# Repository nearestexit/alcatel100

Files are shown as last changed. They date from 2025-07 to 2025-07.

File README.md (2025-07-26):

# alcatel100

Custom keyboard designed to use the GMK keycaps from the [Alcatel-Lucent MMK](https://deskthority.net/viewtopic.php?t=23887).
Designed in Onshape and KiCad.
Powered by [QMK](https://github.com/qmk/qmk_firmware).

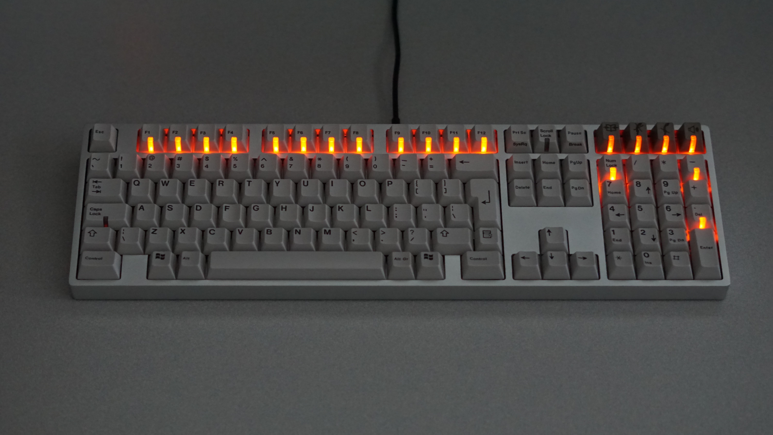
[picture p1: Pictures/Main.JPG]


## Overview
The Alcatel MMK has a beautiful set of keycaps, but the Enter, Backspace, and Right Shift are 0.25u shorter than normal. They are rarely, if ever, used on customs.
The keycaps were originally made by Cherry, but later GMK took over production.

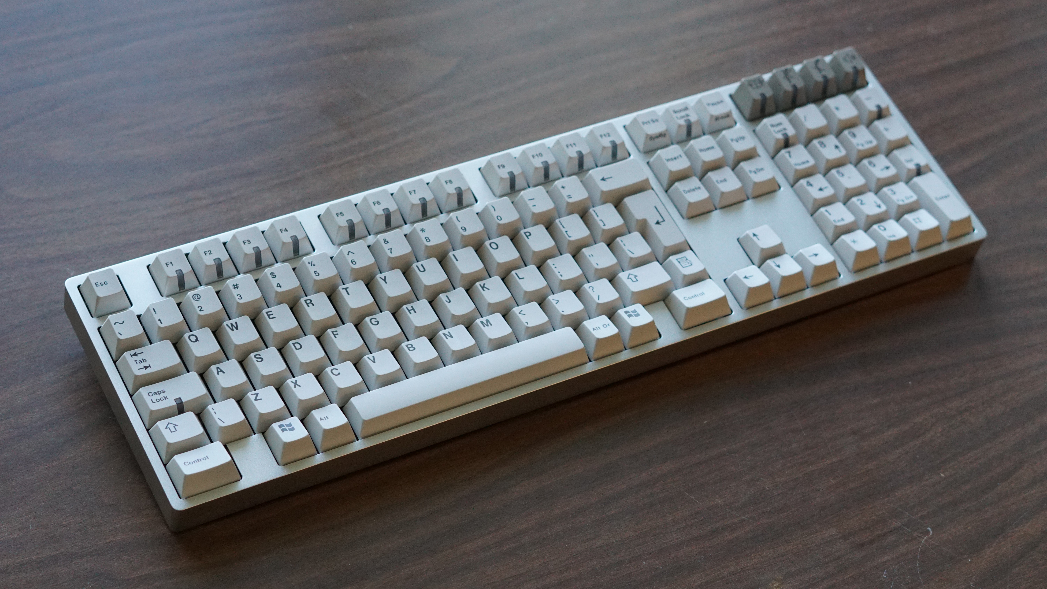
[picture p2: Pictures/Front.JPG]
Front


I designed this for fun. It is not an entry-level keyboard, and it is not intended for a Group Buy.
I'm sharing the production and source files with the goal of serving as a reference for other designers.

combo2

## Design Goals
- Box-on-wedge with seamless sides all around, including the back
- Left half of the keyboard isolated from the right half
- Single-color PWM-dimmable backlight
- Uniform 4.8mm bezels

**Case Source (Onshape):** https://cad.onshape.com/documents/5081b96c77523c56bb0f8f6b/w/91dc47074a8fd3b0ca2e25d0/e/6e8ed4262c52380f9f8bfe9b

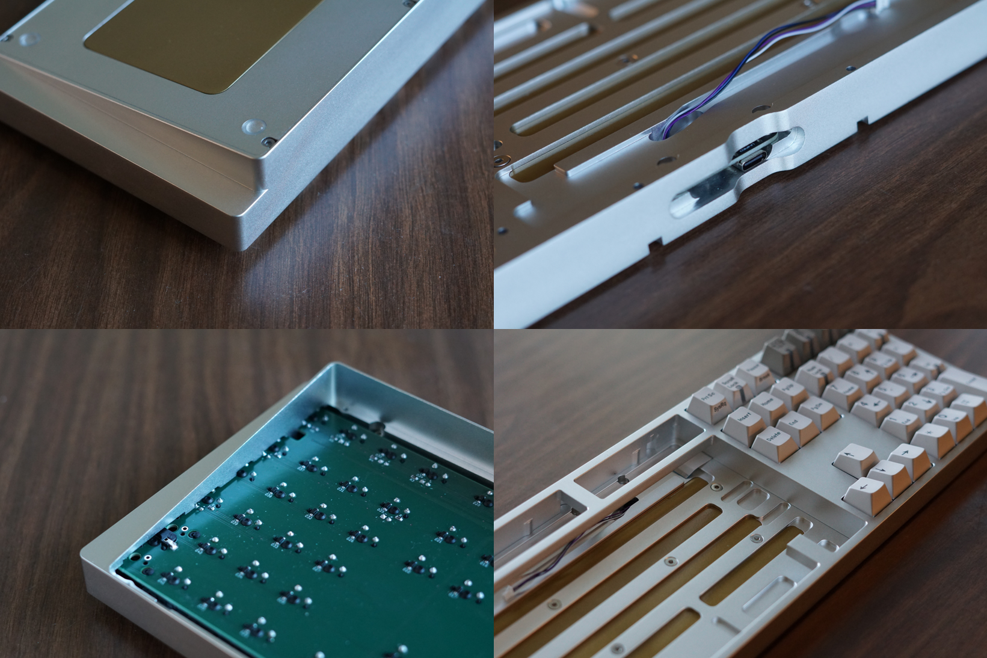
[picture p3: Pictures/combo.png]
Combo


## PCB
The PCB supports both configurations of split right shift, and also split numpad enter. Unfortunately, after the PCB was manufactured, I discovered that the Cherry version of the keyset has a 6.25u spacebar that only has an offset stem, while the GMK version of the keyset has a 6.25u spacebar that supports both centered and offset stems. The PCB and bottom case only support the centered stem location.
I ordered a single bare PCB from EuroCircuits and hand-soldered the components, so I do not have JLCPCB production files available.

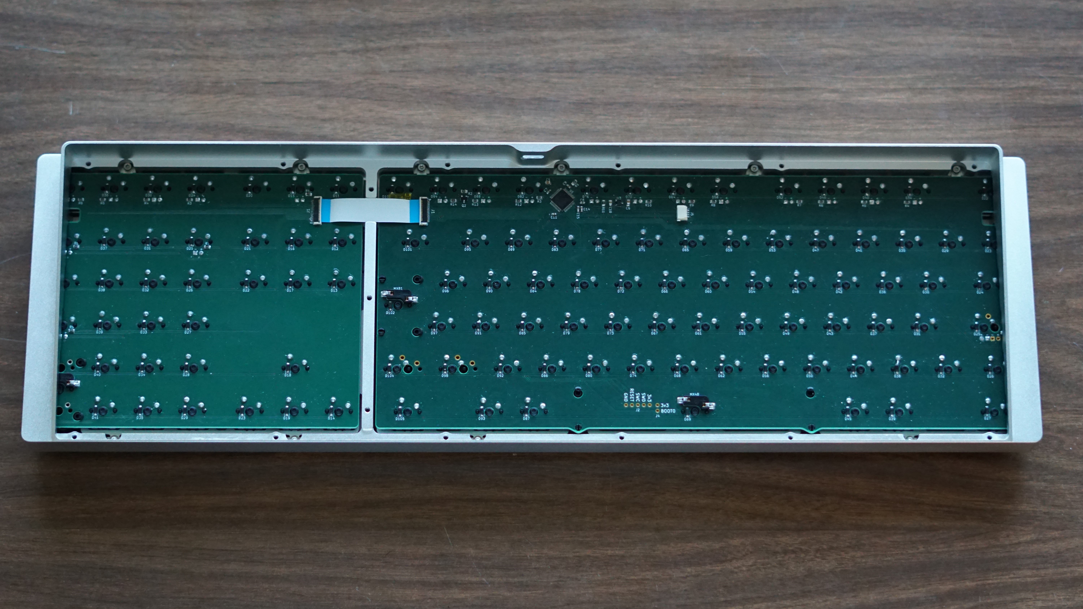
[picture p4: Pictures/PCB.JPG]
PCB


## Bill of Materials

| Item  | Quantity | Link |
| --- | --- | --- |
| Ribbon Cable | 1 | https://www.digikey.com/en/products/detail/molex/0151660207/3281088 |
| 3M SJ5302 | 4  | https://www.3m.com/3M/en_US/p/d/b5005035183/ |
| Unified Daughterboard  | 1  | https://cannonkeys.com/products/unified-daughterboard-and-jst-cable |
| M2.5x0.45x8mm SHCS | 6  | https://www.mcmaster.com/91292A012/ |
| 10cm Molex to JST Cable | 1 | https://cannonkeys.com/products/unified-daughterboard-and-jst-cable |
| M2.5x0.45x16mm SHCS | 1 | https://www.mcmaster.com/91292A018/ |
| M2.5x0.45x20mm SHCS | 6 | https://www.mcmaster.com/91292A019/ |
| M2x0.4x4mm SHCS | 10 | https://www.mcmaster.com/91292A005/ |
| M3x0.5x6mm Countersunk Screw | 5 | https://www.mcmaster.com/92125A126/ |
| M3x0.5x8mm Countersunk Screw | 8 | https://www.mcmaster.com/92125A128/ |

## Backlight

Each lock light is controlled by a separate pin and has a fixed brightness. The remainder of the windowed keys are all on the same PWM dimmable circuit.
I used [these LEDs](https://www.digikey.com/en/products/detail/american-bright-optoelectronics-corporation/BL-B8141-TRS20A/22486924), which have a nice color, but MX LEDs are actually supposed to be 3mm *flangeless* LEDs. These LEDs are *flanged* 3mm. I had to clip off all the flanges (not fun).

backlight

## Firmware

A QMK .bin file is provided for flashing, as well as QMK source files. I can port it to Vial upon request.

## Credits

Everyone in the Keyboard Atelier who has helped me over the past 2 years.

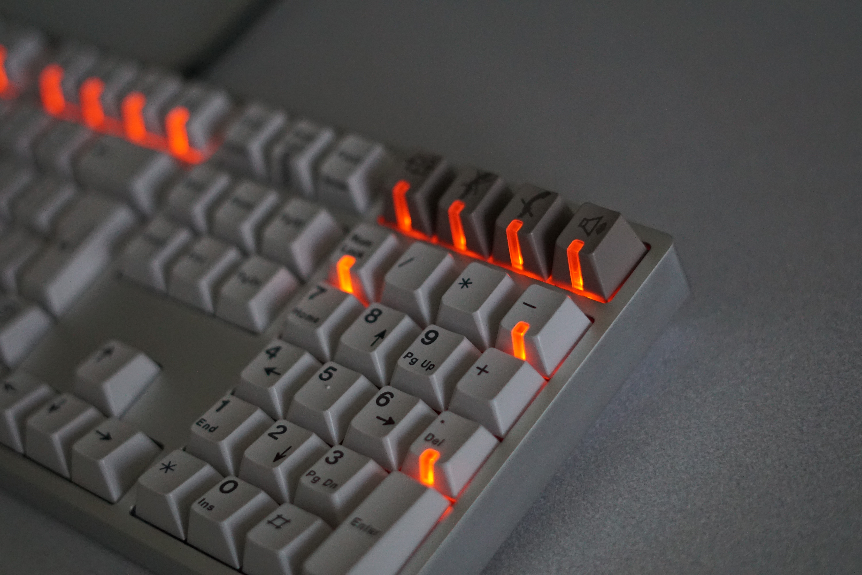
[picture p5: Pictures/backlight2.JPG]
bottom


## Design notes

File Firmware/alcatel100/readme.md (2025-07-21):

# alcatel100

alcatel100

*A short description of the keyboard/project*

* Keyboard Maintainer: [nearestexit](https://github.com/nearestexit)
* Hardware Supported: *The PCBs, controllers supported*
* Hardware Availability: *Links to where you can find this hardware*

Make example for this keyboard (after setting up your build environment):

    make alcatel100:default

Flashing example for this keyboard:

    make alcatel100:default:flash

See the [build environment setup](https://docs.qmk.fm/#/getting_started_build_tools) and the [make instructions](https://docs.qmk.fm/#/getting_started_make_guide) for more information. Brand new to QMK? Start with our [Complete Newbs Guide](https://docs.qmk.fm/#/newbs).

## Bootloader

Enter the bootloader in 3 ways:

* **Bootmagic reset**: Hold down the key at (0,0) in the matrix (usually the top left key or Escape) and plug in the keyboard
* **Physical reset button**: Briefly press the button on the back of the PCB - some may have pads you must short instead
* **Keycode in layout**: Press the key mapped to `QK_BOOT` if it is available

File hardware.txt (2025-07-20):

front case screws
m2.5x8mm alloy steel socket head screws x5
goes through 3.1mm of untapped bottom case before hitting 7mm deep hole, tapped to 6.1mm
https://www.mcmaster.com/91292A012

front (smallest) divider screw 
m2.5x8mm alloy steel socket head screws x1
goes through 1.8mm of untapped bottom case before hitting hole tapped to 9.6mm
https://www.mcmaster.com/91292A012

middle divider screw
m2.5x16 alloy steel socket head screw x1
goes through 7.9mm of untapped bottom case before hitting hole tapped to 9.6mm
https://www.mcmaster.com/91292A018/

rear (longest) divider screw
m2.5x20 alloy steel socket head screw x1
goes through 14.11mm to untapped bottom case before hitting hole tapped to 9.6mm
https://www.mcmaster.com/91292A019/

rear case screws
m2.5x20 alloy steel socket head screws x5
goes through 15.5mm of untapped bottom case before hitting hole tapped to 6.1mm
https://www.mcmaster.com/91292A019/

plate screws
m2x4mm alloy steel socket head screws x10
goes through 1.6mm of untapped plate before hitting hitting hole tapped to 3.8mm
https://www.mcmaster.com/91292A005/

short weight screws
m3x6mm countersunk alloy steel hex drive flat head screws x5
goes through 2.5mm of untapped bottom case before hitting hole tapped to 4mm
https://www.mcmaster.com/92125A126/

medium & long weight screws
m3x8mm countersunk alloy steel hex drive flat head screws x8
goes through 4.5mm of untapped bottom case before hitting hole tapped to 4mm
https://www.mcmaster.com/92125A128/

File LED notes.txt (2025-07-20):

We have 18 LEDs on our backlight

https://www.digikey.com/en/products/detail/american-bright-optoelectronics-corporation/BL-B8141-TRS20A/22486924

forward voltage = 2 V

We choose:
R = 470

V/R = I = 2/470 = 0.0043 A = 4.3 mA
18*4.3 = 77.4 mA

irlml2502 has plenty of current to power this. https://www.infineon.com/dgdl/irlml2502pbf.pdf?fileId=5546d462533600a401535668048e2606

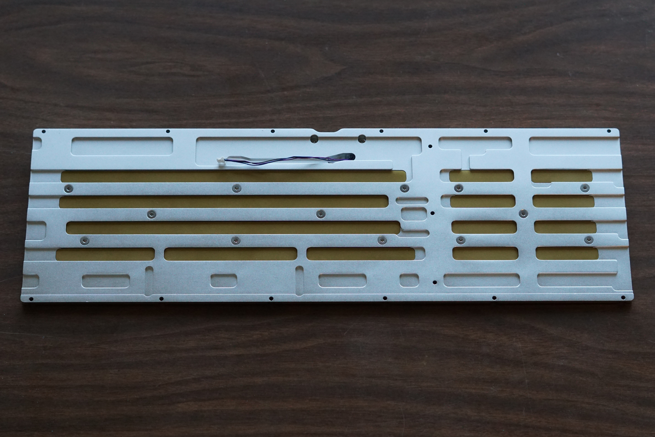
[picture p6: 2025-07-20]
Pictures/insidebottom.JPG

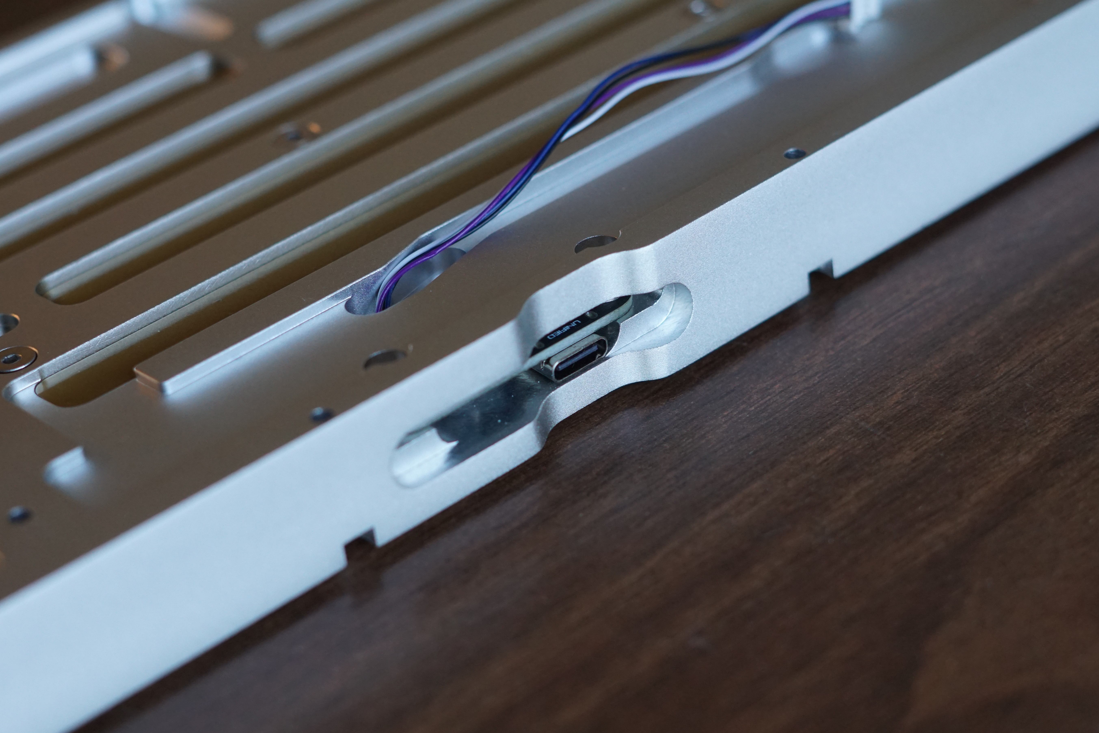
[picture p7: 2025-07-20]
Pictures/udb.JPG

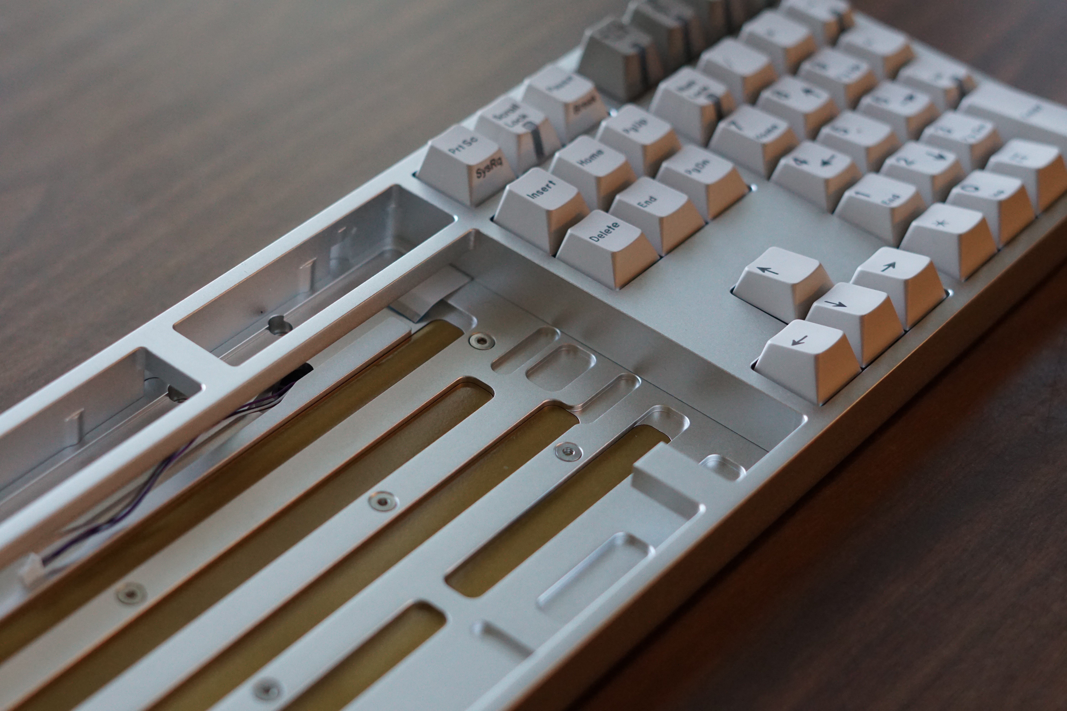
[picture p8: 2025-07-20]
Pictures/isolation.JPG

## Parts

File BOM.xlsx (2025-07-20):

Item | Quantity | Material | Surface Treatment
Top Case | 1 | 6061 Aluminum | Bead blast, anodize silver
Bottom Case | 1 | 6061 Aluminum | Bead blast, anodize silver
Left Plate | 1 | 6061 Aluminum | Bead blast, anodize silver
Right Plate | 1 | 6061 Aluminum | Bead blast, anodize silver
Left Weight | 1 | Brass | Bead blast, clear coat
Right Weight | 1 | Brass | Bead blast, clear coat

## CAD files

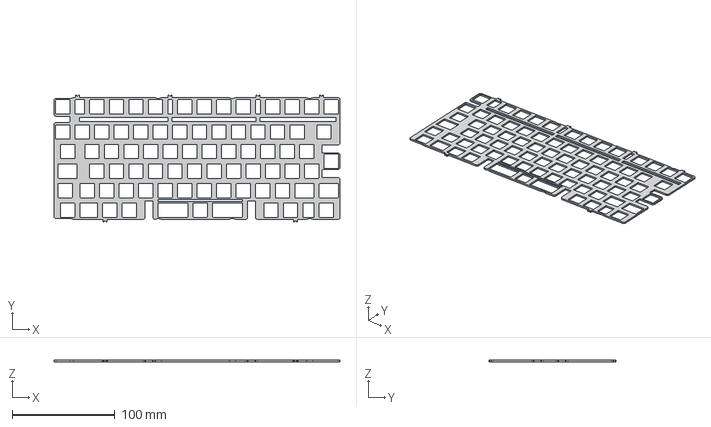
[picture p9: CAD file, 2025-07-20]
Case/Left Plate.step
278.9 x 124.0 x 1.60 mm

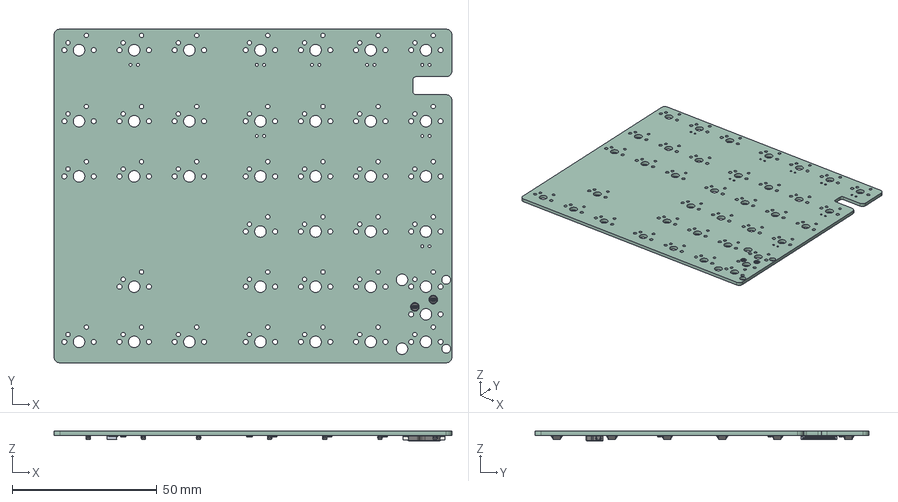
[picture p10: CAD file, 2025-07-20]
PCB/AlcatelRightPCB/AlcatelRightPCB.step
137.5 x 115.2 x 3.47 mm
D_SOD_123 x 37
R_0805_2012Metric x 8
P10051922_2010ELF
Kailh Hotswap v2
AlcatelRightPCB_PCB

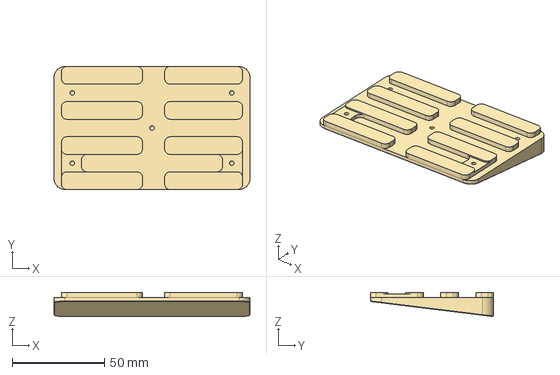
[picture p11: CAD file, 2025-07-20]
Case/Right Weight.step
106.4 x 66.7 x 13.0 mm

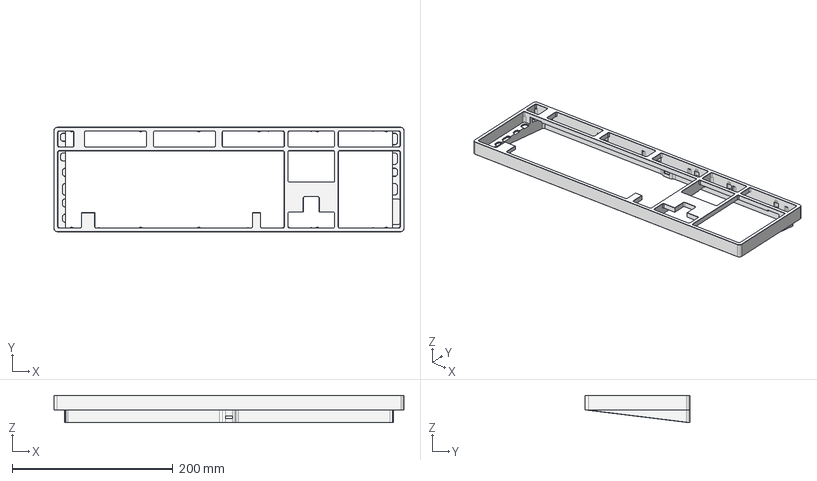
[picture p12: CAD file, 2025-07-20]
Case/Top Case.step
435.6 x 130.1 x 34.2 mm

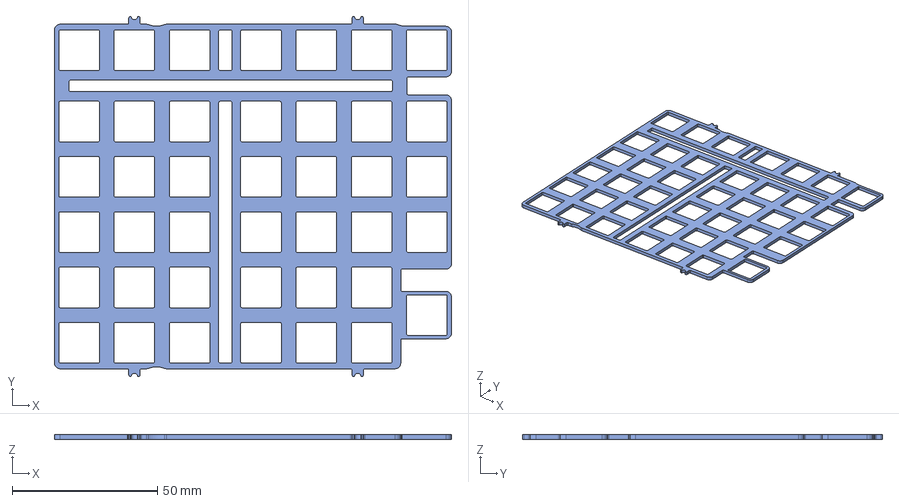
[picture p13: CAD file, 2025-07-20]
Case/Right Plate.step
136.8 x 124.0 x 1.60 mm

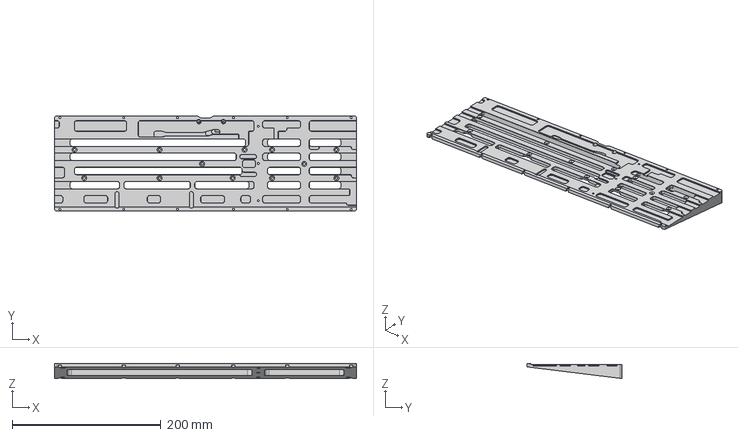
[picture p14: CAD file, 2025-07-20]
Case/Bottom Case.step
406.2 x 127.7 x 20.3 mm

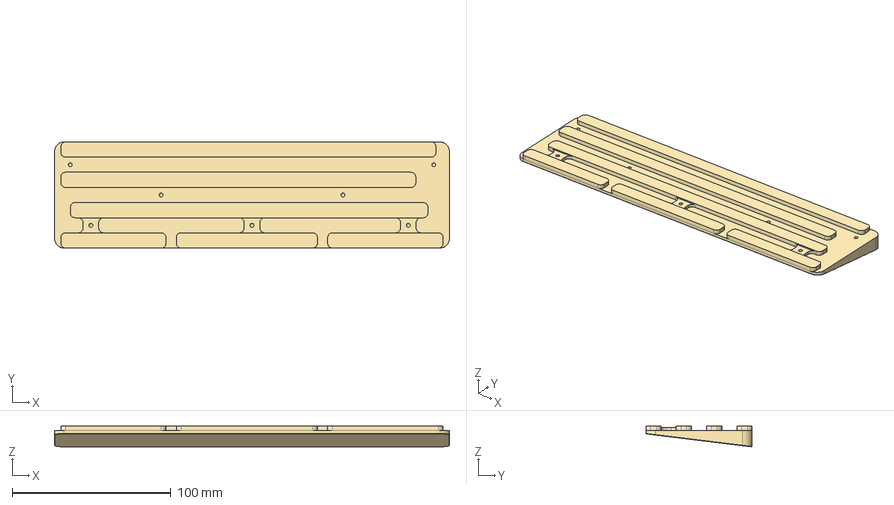
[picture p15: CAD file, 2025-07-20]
Case/Left Weight.step
248.5 x 66.7 x 13.0 mm

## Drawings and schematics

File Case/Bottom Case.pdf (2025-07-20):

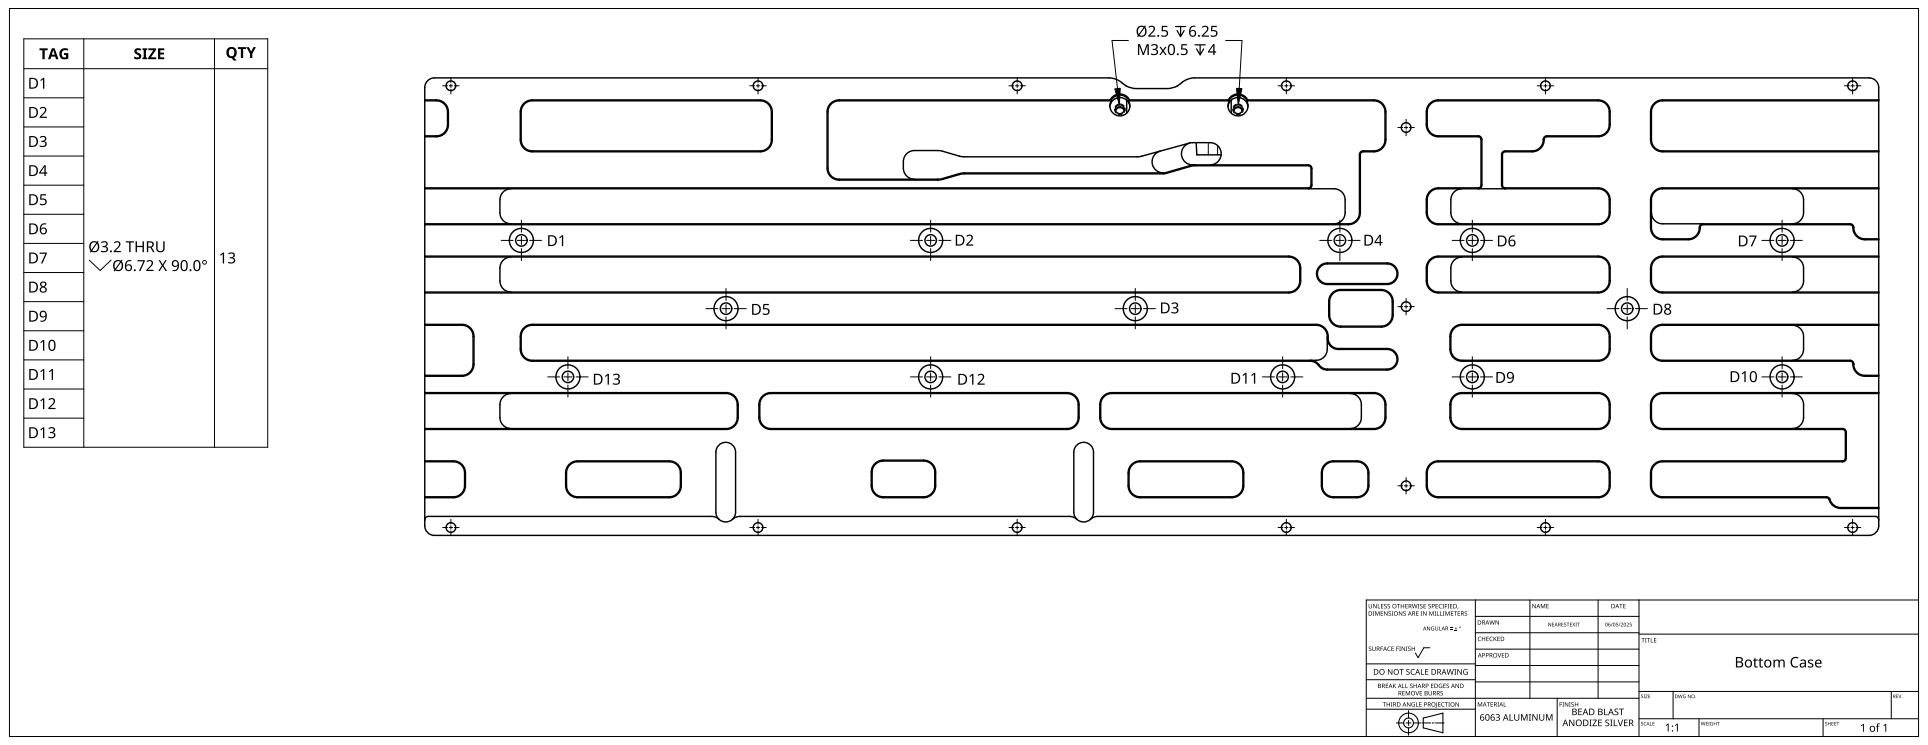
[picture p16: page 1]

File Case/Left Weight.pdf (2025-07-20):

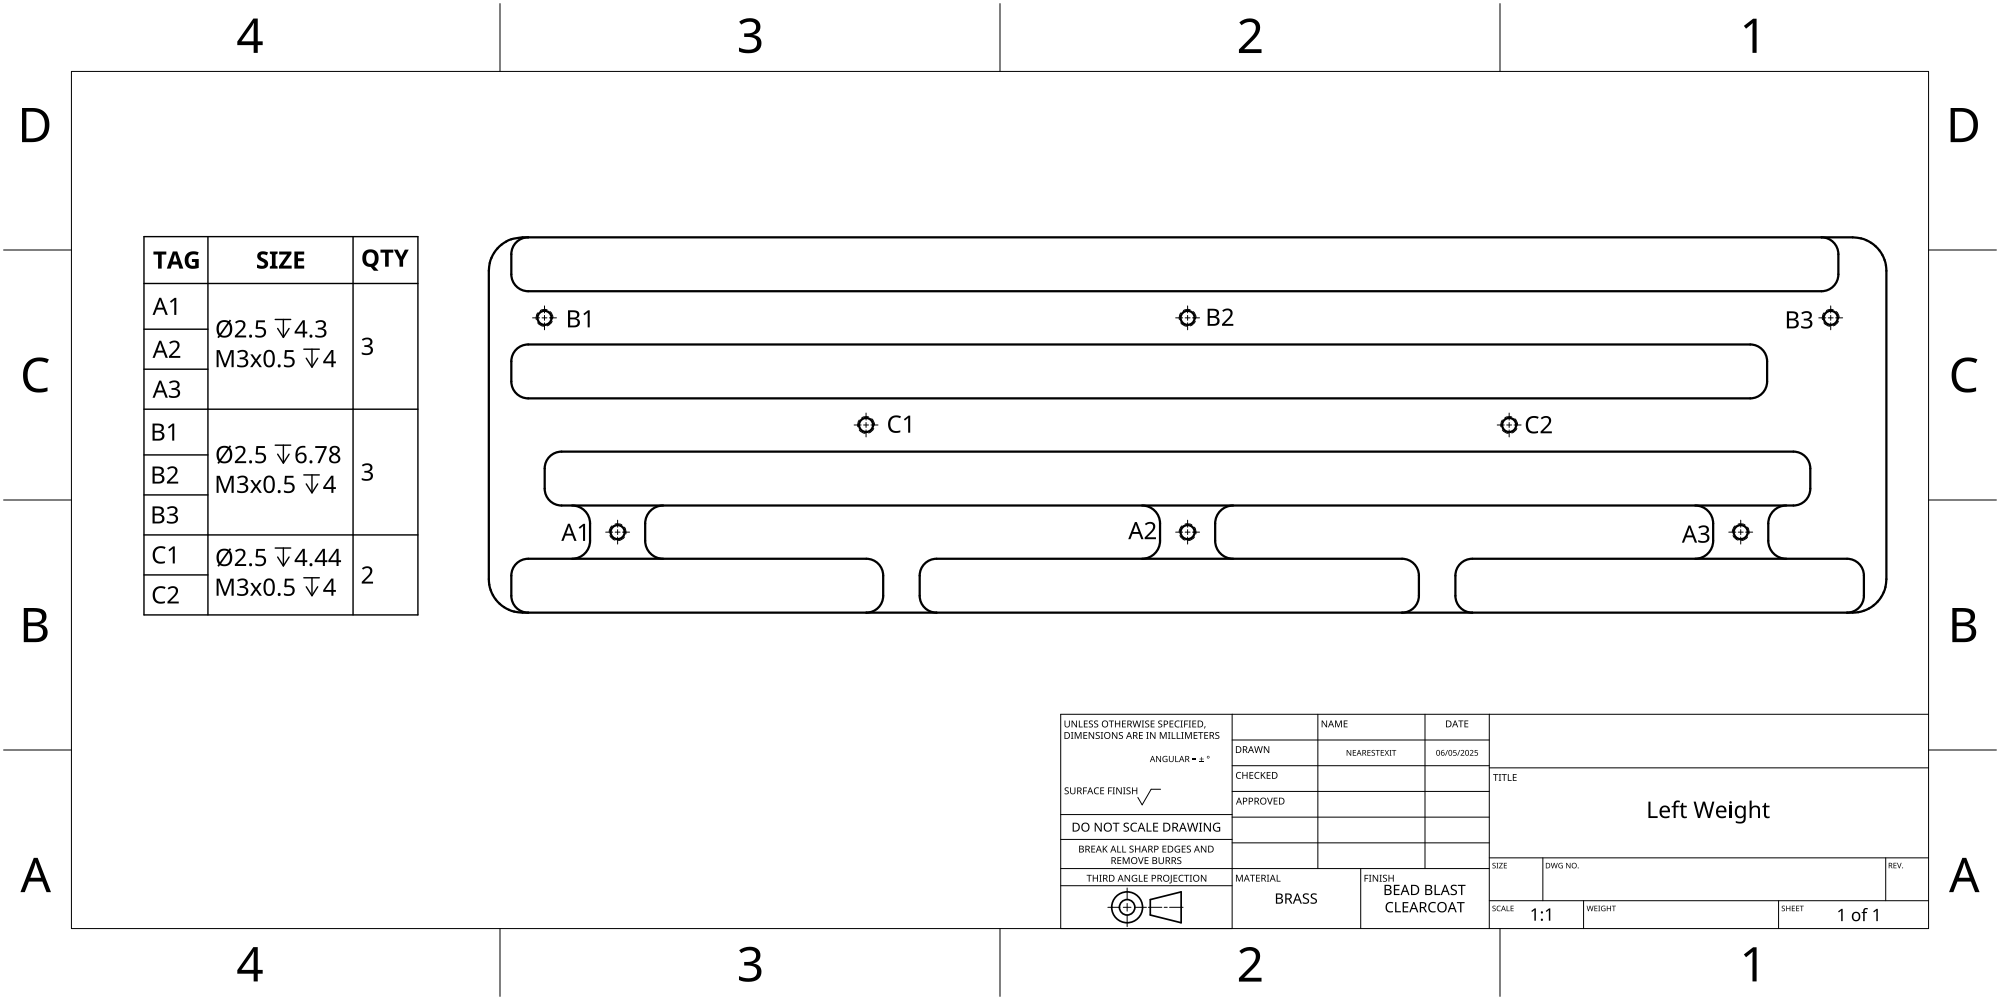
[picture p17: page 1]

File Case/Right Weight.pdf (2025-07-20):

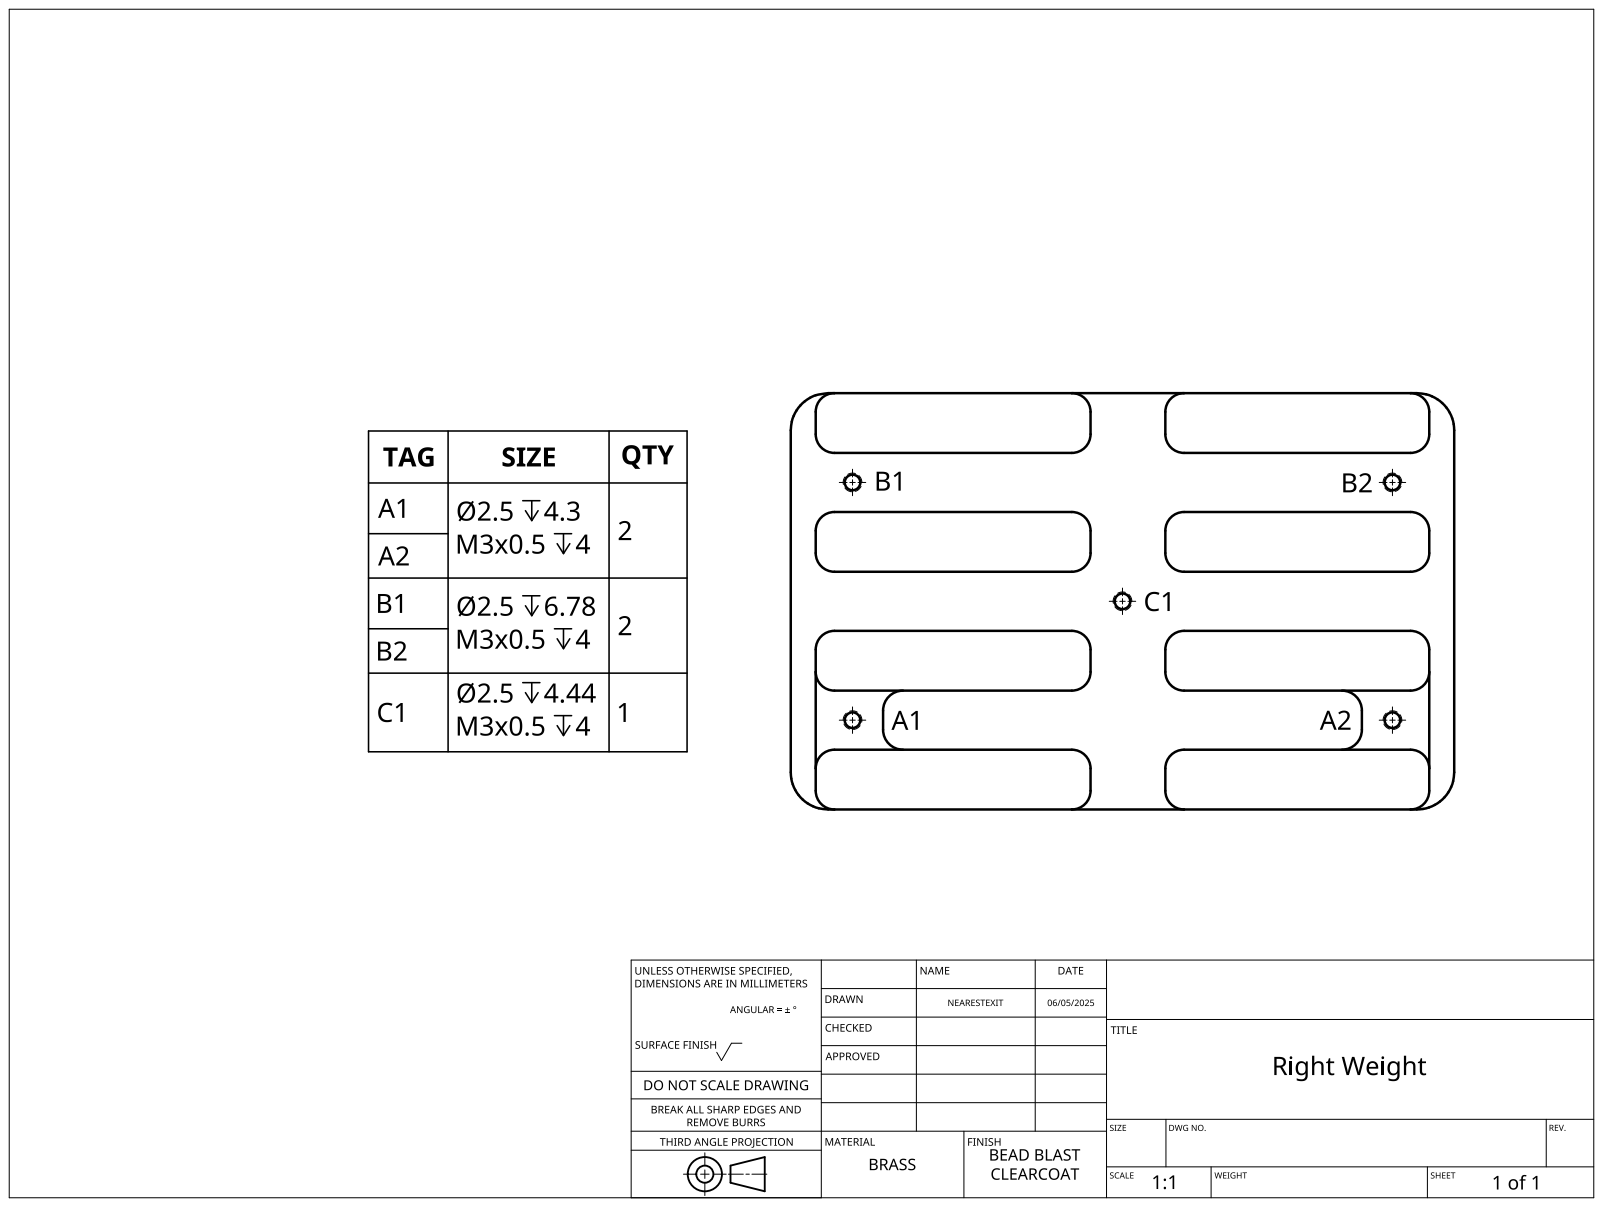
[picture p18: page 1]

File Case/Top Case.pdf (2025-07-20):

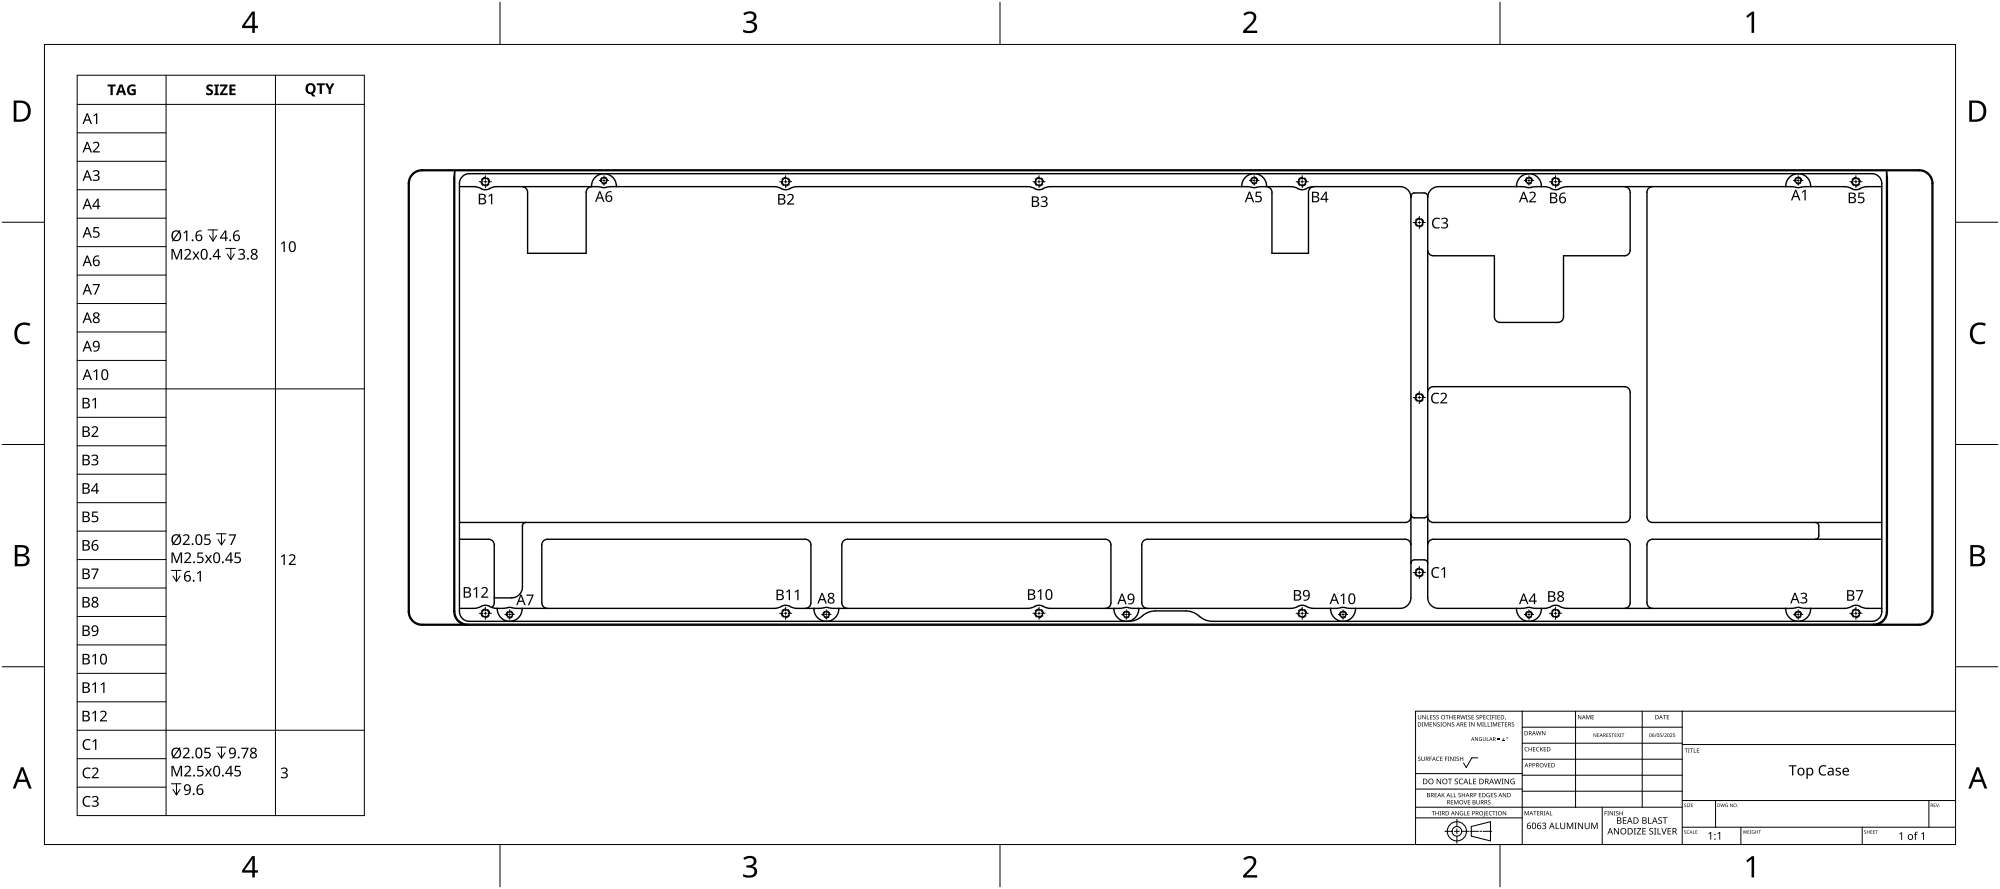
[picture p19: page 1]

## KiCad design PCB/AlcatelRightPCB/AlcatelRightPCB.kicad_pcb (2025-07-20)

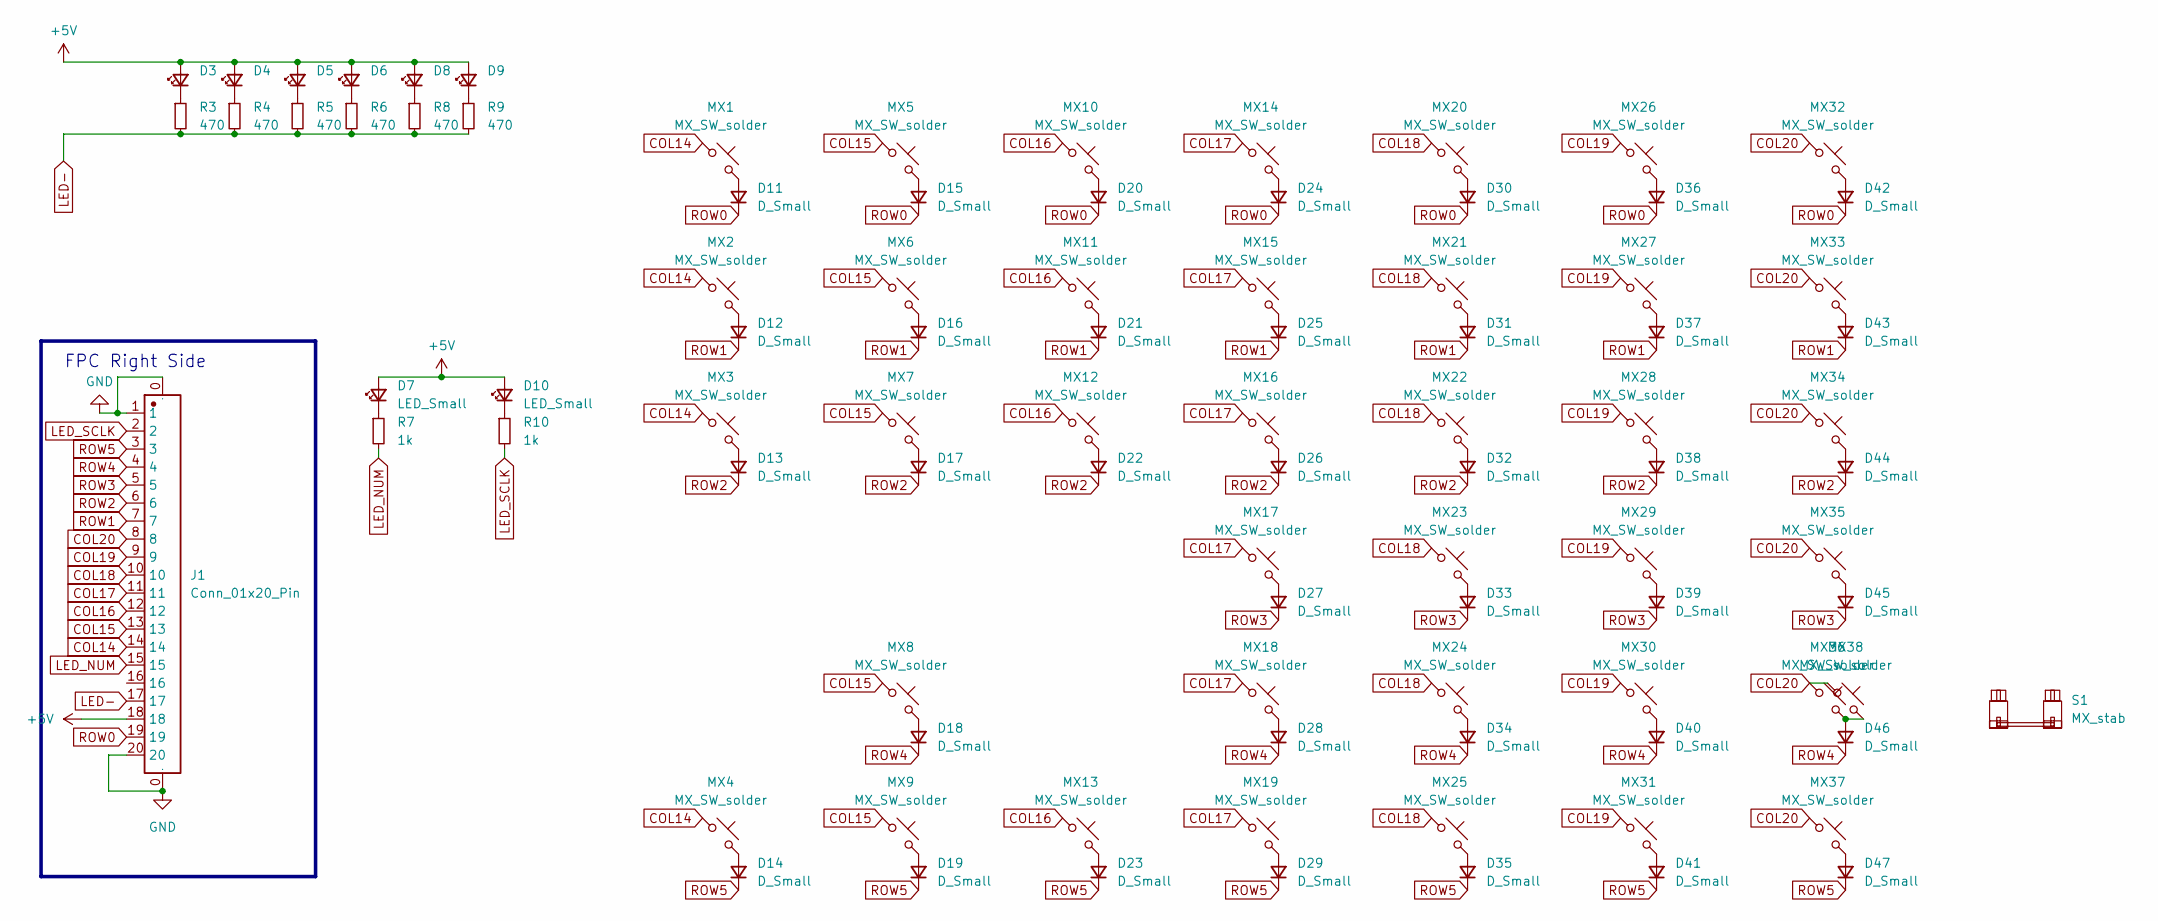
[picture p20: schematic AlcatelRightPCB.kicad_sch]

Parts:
D3, D4, D5, D6, D8, D9: LED_MX_3mm_Offset
D7, D10: LED_Small; LED_MX_3mm_Offset
D11, D12, D13, D14, D15, D16, D17, D18, D19, D20, D21, D22, D23, D24, D25, D26, D27, D28, D29, D30, D31, D32, D33, D34, D35, D36, D37, D38, D39, D40, D41, D42, D43, D44, D45, D46, D47: D_Small; D_SOD-123_ShiftedSilkscreen
J1: Conn_01x20_Pin; CONN-SMD_20P-P0.50_10051922-2010ELF
MX1, MX2, MX3, MX4, MX5, MX6, MX7, MX8, MX9, MX10, MX11, MX12, MX13, MX14, MX15, MX16, MX17, MX18, MX19, MX20, MX21, MX22, MX23, MX24, MX25, MX26, MX27, MX28, MX29, MX30, MX31, MX32, MX33, MX34, MX35, MX36, MX37: MX_SW_solder; SW_MX_1u
MX38: MX_SW_solder; SW_MX_HS_CPG151101S11_No_PTH_Edge
R3, R4, R5, R6, R8, R9: 470; R_0805_2012Metric
R7, R10: 1k; R_0805_2012Metric
S1: MX_stab; STAB_MX_2u

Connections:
+5V: D3.2 (A), D4.2 (A), D5.2 (A), D6.2 (A), D7.2 (A), D8.2 (A), D9.2 (A), D10.2 (A), J1.18
COL14: J1.14, MX1.1, MX2.1, MX3.1, MX4.1
COL15: J1.13, MX5.1, MX6.1, MX7.1, MX8.1, MX9.1
COL16: J1.12, MX10.1, MX11.1, MX12.1, MX13.1
COL17: J1.11, MX14.1, MX15.1, MX16.1, MX17.1, MX18.1, MX19.1
COL18: J1.10, MX20.1, MX21.1, MX22.1, MX23.1, MX24.1, MX25.1
COL19: J1.9, MX26.1, MX27.1, MX28.1, MX29.1, MX30.1, MX31.1
COL20: J1.8, MX32.1, MX33.1, MX34.1, MX35.1, MX36.1, MX37.1, MX38.1
GND: J1.0, J1.1, J1.20
LED-: J1.17, R3.2, R4.2, R5.2, R6.2, R8.2, R9.2
LED_NUM: J1.15, R7.2
LED_SCLK: J1.2, R10.2
unnamed: D3.1 (K), R3.1
unnamed: D4.1 (K), R4.1
unnamed: D5.1 (K), R5.1
unnamed: D6.1 (K), R6.1
unnamed: D7.1 (K), R7.1
unnamed: D8.1 (K), R8.1
unnamed: D9.1 (K), R9.1
unnamed: D10.1 (K), R10.1
unnamed: D11.2 (A), MX1.2
unnamed: D12.2 (A), MX2.2
unnamed: D13.2 (A), MX3.2
unnamed: D14.2 (A), MX4.2
unnamed: D15.2 (A), MX5.2
unnamed: D16.2 (A), MX6.2
unnamed: D17.2 (A), MX7.2
unnamed: D18.2 (A), MX8.2
unnamed: D19.2 (A), MX9.2
unnamed: D20.2 (A), MX10.2
unnamed: D21.2 (A), MX11.2
unnamed: D22.2 (A), MX12.2
unnamed: D23.2 (A), MX13.2
unnamed: D24.2 (A), MX14.2
unnamed: D25.2 (A), MX15.2
unnamed: D26.2 (A), MX16.2
unnamed: D27.2 (A), MX17.2
unnamed: D28.2 (A), MX18.2
unnamed: D29.2 (A), MX19.2
unnamed: D30.2 (A), MX20.2
unnamed: D31.2 (A), MX21.2
unnamed: D32.2 (A), MX22.2
unnamed: D33.2 (A), MX23.2
unnamed: D34.2 (A), MX24.2
unnamed: D35.2 (A), MX25.2
unnamed: D36.2 (A), MX26.2
unnamed: D37.2 (A), MX27.2
unnamed: D38.2 (A), MX28.2
unnamed: D39.2 (A), MX29.2
unnamed: D40.2 (A), MX30.2
unnamed: D41.2 (A), MX31.2
unnamed: D42.2 (A), MX32.2
unnamed: D43.2 (A), MX33.2
unnamed: D44.2 (A), MX34.2
unnamed: D45.2 (A), MX35.2
unnamed: D46.2 (A), MX36.2, MX38.2
unnamed: D47.2 (A), MX37.2
ROW0: D11.1 (K), D15.1 (K), D20.1 (K), D24.1 (K), D30.1 (K), D36.1 (K), D42.1 (K), J1.19
ROW1: D12.1 (K), D16.1 (K), D21.1 (K), D25.1 (K), D31.1 (K), D37.1 (K), D43.1 (K), J1.7
ROW2: D13.1 (K), D17.1 (K), D22.1 (K), D26.1 (K), D32.1 (K), D38.1 (K), D44.1 (K), J1.6
ROW3: D27.1 (K), D33.1 (K), D39.1 (K), D45.1 (K), J1.5
ROW4: D18.1 (K), D28.1 (K), D34.1 (K), D40.1 (K), D46.1 (K), J1.4
ROW5: D14.1 (K), D19.1 (K), D23.1 (K), D29.1 (K), D35.1 (K), D41.1 (K), D47.1 (K), J1.3

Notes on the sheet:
FPC Right Side

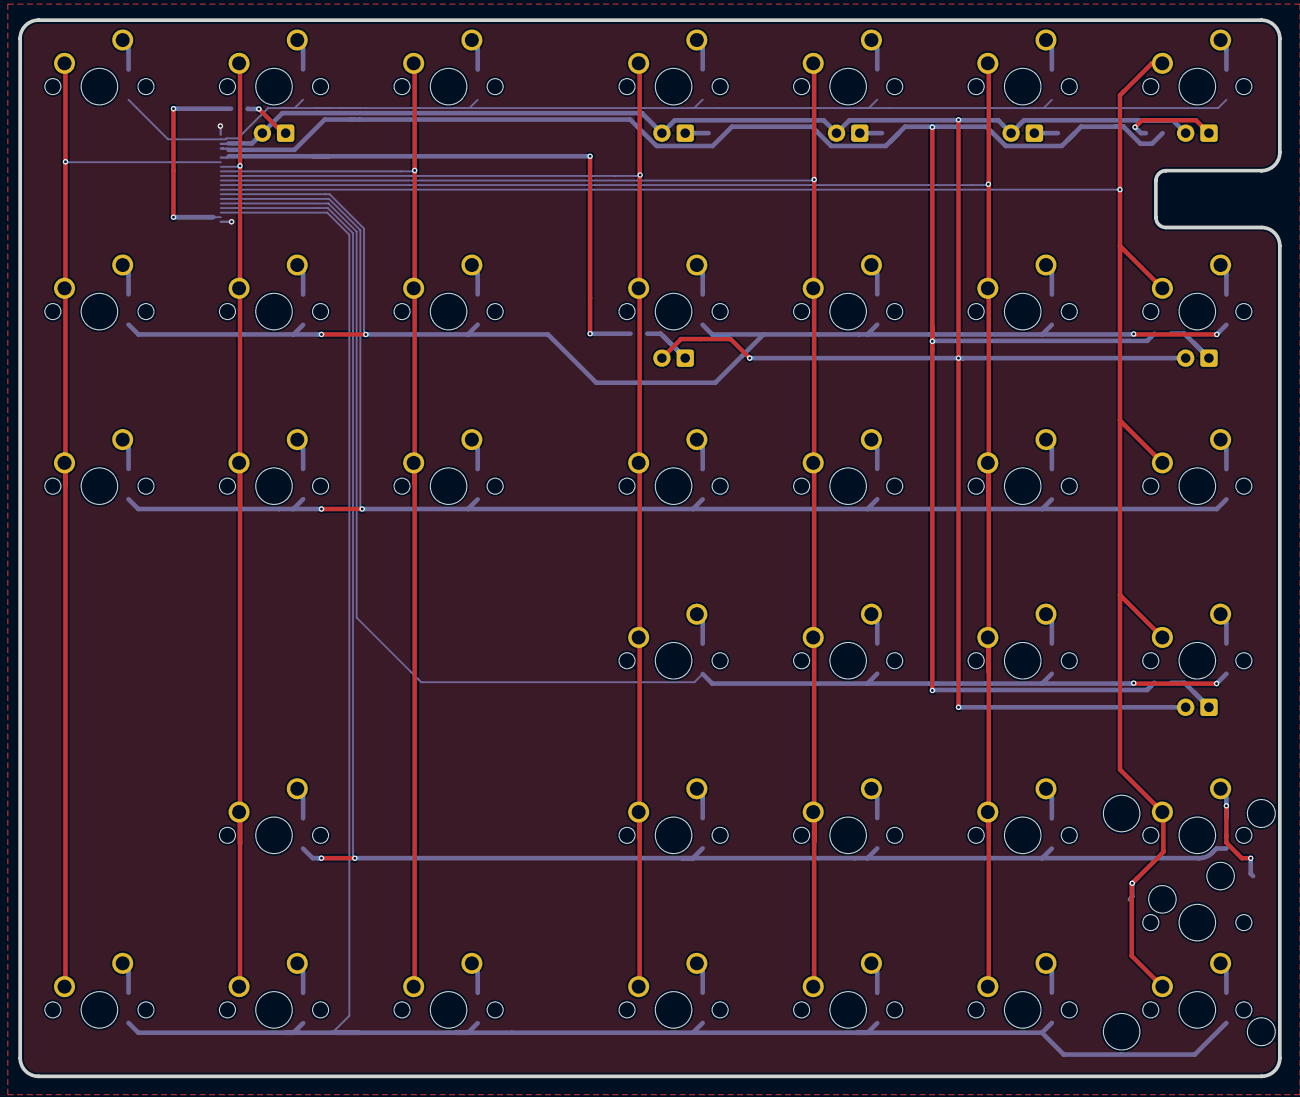
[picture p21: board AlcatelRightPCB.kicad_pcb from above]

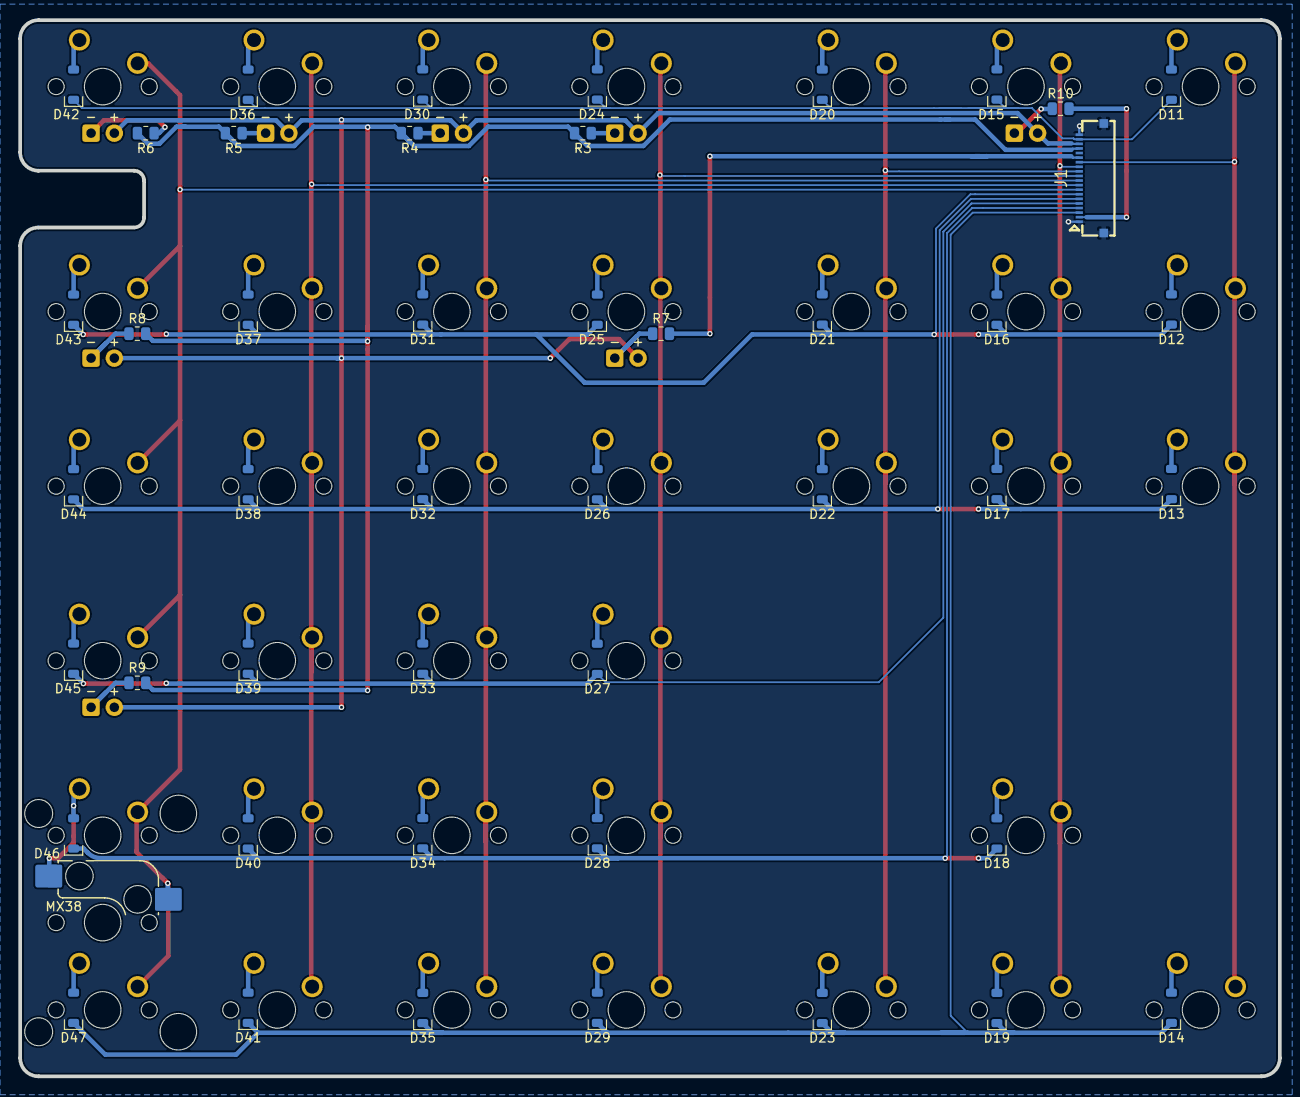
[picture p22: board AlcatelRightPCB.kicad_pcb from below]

Board: 2 copper layers, 137.5 x 115.2 mm, 93 parts (47 on the bottom side), 63 nets.

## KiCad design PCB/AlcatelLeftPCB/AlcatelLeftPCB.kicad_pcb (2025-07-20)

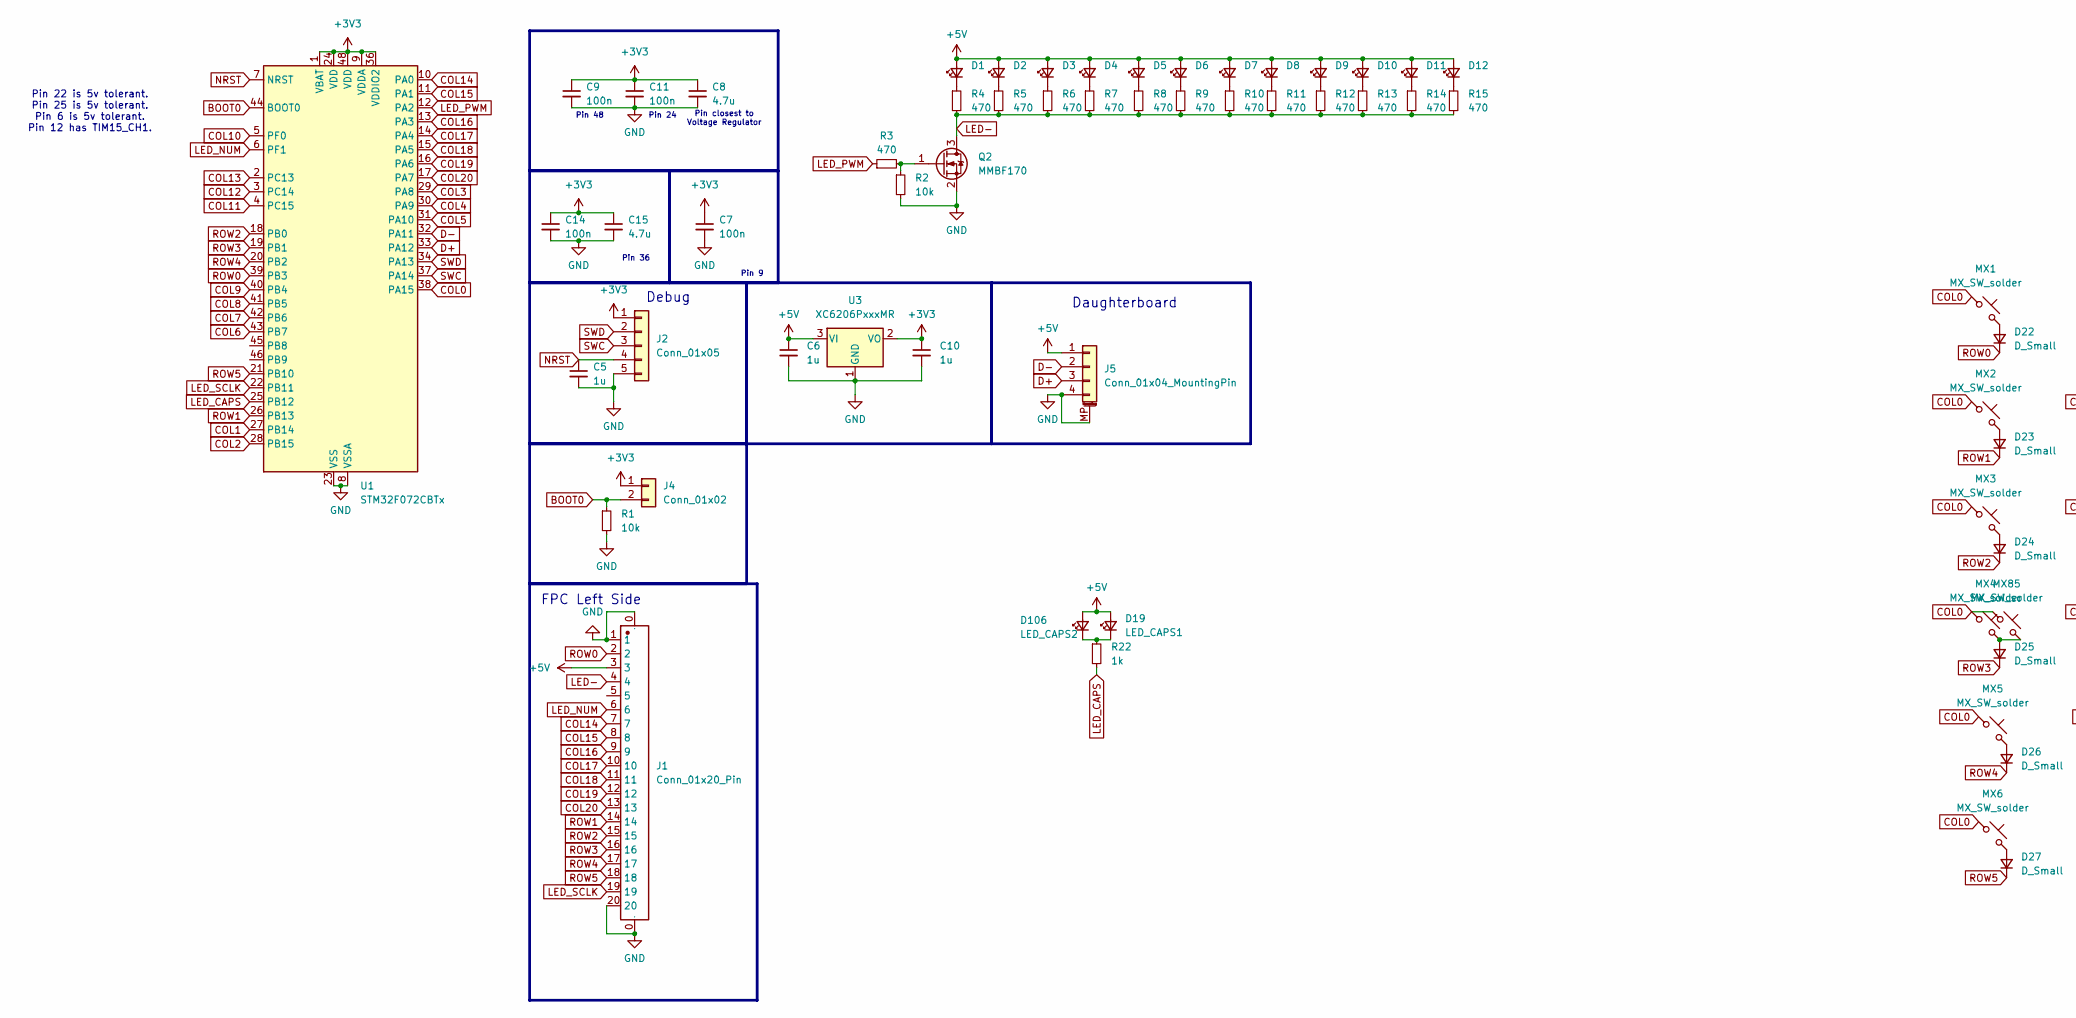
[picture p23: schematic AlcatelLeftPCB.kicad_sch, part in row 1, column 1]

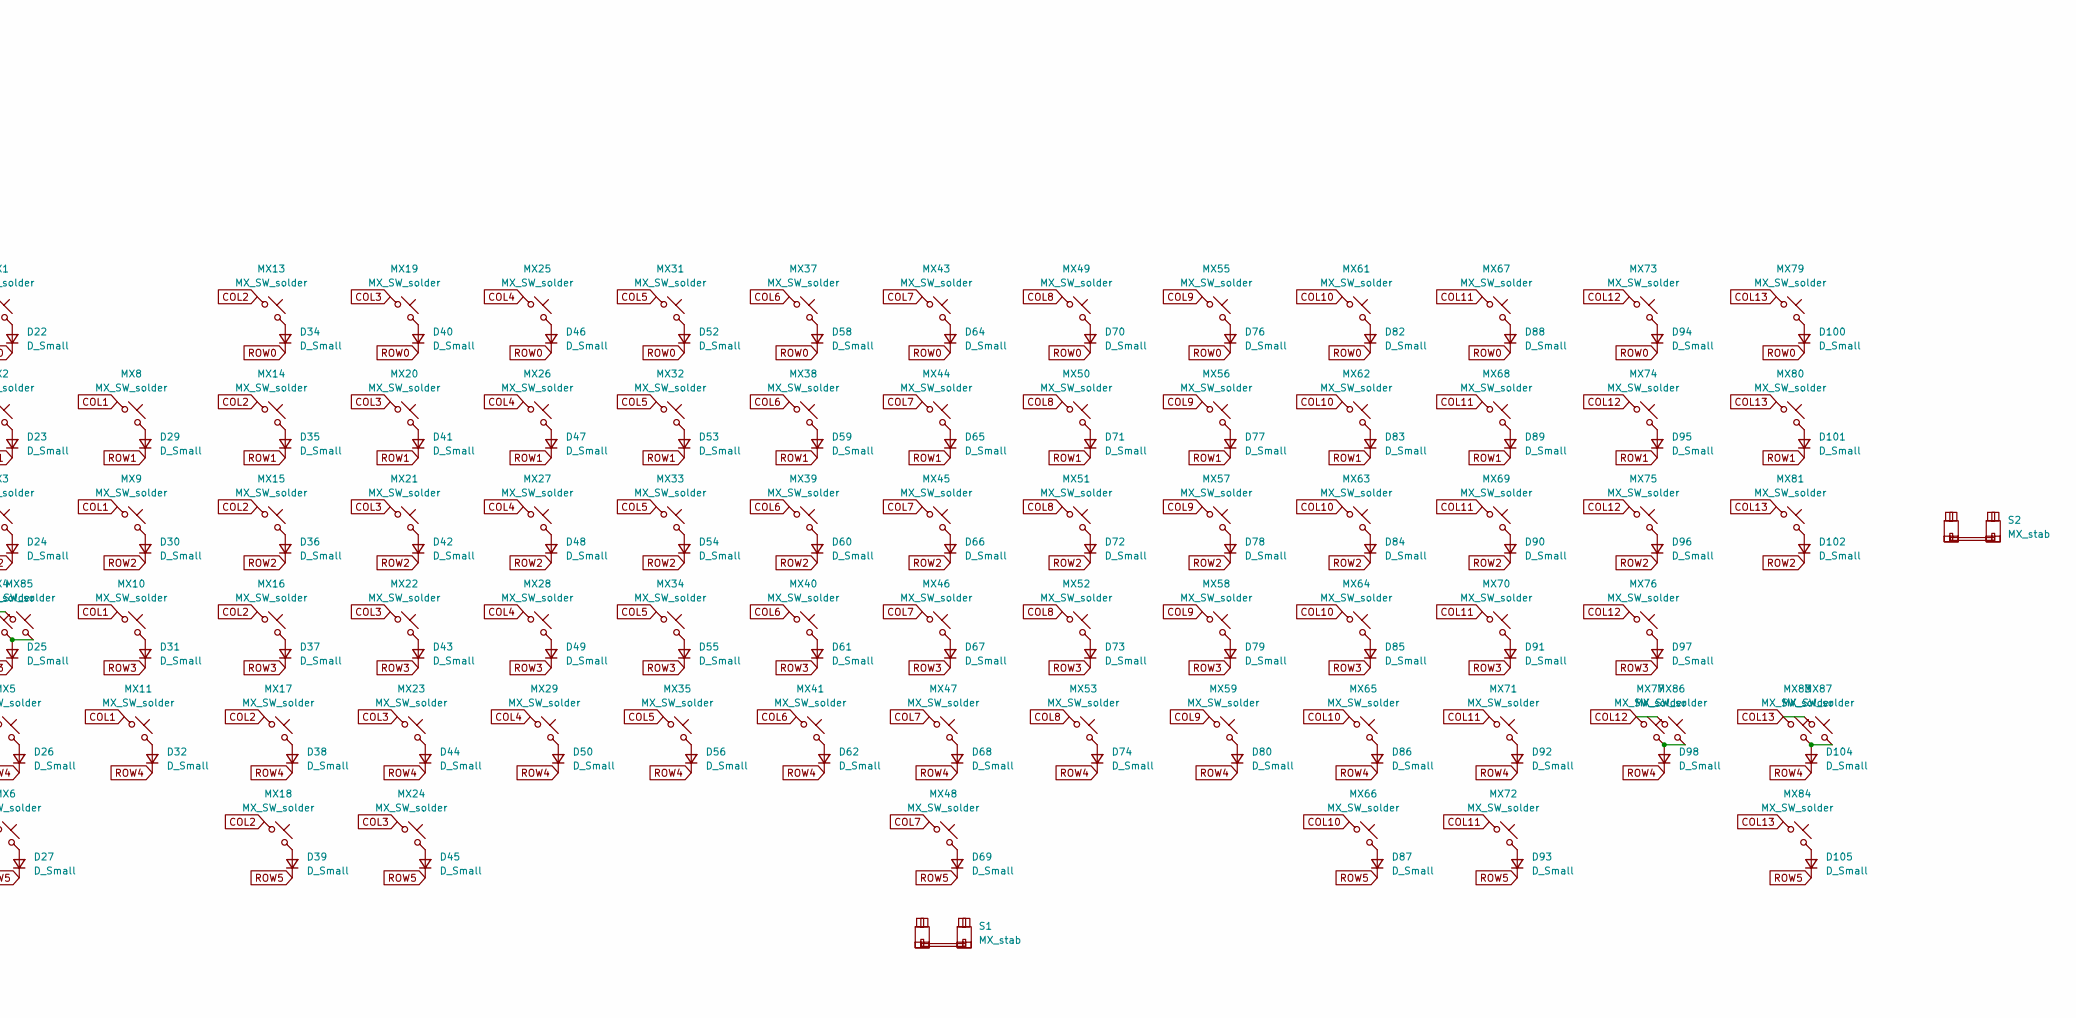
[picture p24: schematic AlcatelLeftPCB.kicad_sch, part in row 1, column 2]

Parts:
C5, C6, C10: 1u; C_0805_2012Metric
C7, C9, C11, C14: 100n; C_0603_1608Metric
C8, C15: 4.7u; C_0603_1608Metric
D1, D2, D3, D4, D5, D6, D7, D8, D9, D10, D11, D12: LED_MX_3mm_Offset
D19: LED_CAPS1; LED_MX_3mm_Offset_Flipped
D22, D23, D24, D25, D26, D27, D29, D30, D31, D32, D34, D35, D36, D37, D38, D39, D40, D41, D42, D43, D44, D45, D46, D47, D48, D49, D50, D52, D53, D54, D55, D56, D58, D59, D60, D61, D62, D64, D65, D66, D67, D68, D69, D70, D71, D72, D73, D74, D76, D77, D78, D79, D80, D82, D83, D84, D85, D86, D87, D88, D89, D90, D91, D92, D93, D94, D95, D96, D97, D98, D100, D101, D102, D104, D105: D_Small; D_SOD-123_ShiftedSilkscreen
D106: LED_CAPS2; LED_MX_3mm_Offset
J1: Conn_01x20_Pin; CONN-SMD_20P-P0.50_10051922-2010ELF
J2: Conn_01x05; PinHeader_1x05_P2.54mm_DEBUG
J4: Conn_01x02; PinHeader_1x02_P2.54mm_BOOT
J5: Conn_01x04_MountingPin; JST_SH_SM04B-SRSS-TB_1x04-1MP_P1.00mm_Horizontal
MX1, MX2, MX3, MX4, MX5, MX6, MX8, MX9, MX10, MX11, MX13, MX14, MX15, MX16, MX17, MX18, MX19, MX20, MX21, MX22, MX23, MX24, MX25, MX26, MX27, MX28, MX29, MX31, MX32, MX33, MX34, MX35, MX37, MX38, MX39, MX40, MX41, MX43, MX44, MX45, MX46, MX47, MX49, MX50, MX51, MX52, MX53, MX55, MX56, MX57, MX58, MX59, MX61, MX62, MX63, MX64, MX65, MX66, MX67, MX68, MX69, MX70, MX71, MX72, MX73, MX74, MX75, MX76, MX77, MX79, MX80, MX83, MX84, MX85, MX86, MX87: MX_SW_solder; SW_MX_1u
MX48, MX81: MX_SW_solder; SW_MX_HS_CPG151101S11_0.125ring
Q2: MMBF170; SOT-23
R1, R2: 10k; R_0805_2012Metric
R3, R4, R5, R6, R7, R8, R9, R10, R11, R12, R13, R14, R15: 470; R_0805_2012Metric
R22: 1k; R_0805_2012Metric
S1: MX_stab; STAB_MX_6.25u
S2: MX_stab; STAB_MX_2u
U1: STM32F072CBTx; LQFP-48_7x7mm_P0.5mm
U3: XC6206PxxxMR; SOT-23-3

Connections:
+3V3: C7.1, C8.1, C9.1, C10.1, C11.1, C14.1, C15.1, J2.1, J4.1, U1.1 (VBAT), U1.9 (VDDA), U1.24 (VDD), U1.36 (VDDIO2), U1.48 (VDD), U3.2 (VO)
+5V: C6.1, D1.2 (A), D2.2 (A), D3.2 (A), D4.2 (A), D5.2 (A), D6.2 (A), D7.2 (A), D8.2 (A), D9.2 (A), D10.2 (A), D11.2 (A), D12.2 (A), D19.2 (A), D106.2 (A), J1.3, J5.1, U3.3 (VI)
BOOT0: J4.2, R1.1, U1.44 (BOOT0)
COL0: MX1.1, MX2.1, MX3.1, MX4.1, MX5.1, MX6.1, MX85.1, U1.38 (PA15)
COL1: MX8.1, MX9.1, MX10.1, MX11.1, U1.27 (PB14)
COL2: MX13.1, MX14.1, MX15.1, MX16.1, MX17.1, MX18.1, U1.28 (PB15)
COL3: MX19.1, MX20.1, MX21.1, MX22.1, MX23.1, MX24.1, U1.29 (PA8)
COL4: MX25.1, MX26.1, MX27.1, MX28.1, MX29.1, U1.30 (PA9)
COL5: MX31.1, MX32.1, MX33.1, MX34.1, MX35.1, U1.31 (PA10)
COL6: MX37.1, MX38.1, MX39.1, MX40.1, MX41.1, U1.43 (PB7)
COL7: MX43.1, MX44.1, MX45.1, MX46.1, MX47.1, MX48.1, U1.42 (PB6)
COL8: MX49.1, MX50.1, MX51.1, MX52.1, MX53.1, U1.41 (PB5)
COL9: MX55.1, MX56.1, MX57.1, MX58.1, MX59.1, U1.40 (PB4)
COL10: MX61.1, MX62.1, MX63.1, MX64.1, MX65.1, MX66.1, U1.5 (PF0)
COL11: MX67.1, MX68.1, MX69.1, MX70.1, MX71.1, MX72.1, U1.4 (PC15)
COL12: MX73.1, MX74.1, MX75.1, MX76.1, MX77.1, MX86.1, U1.3 (PC14)
COL13: MX79.1, MX80.1, MX81.1, MX83.1, MX84.1, MX87.1, U1.2 (PC13)
COL14: J1.7, U1.10 (PA0)
COL15: J1.8, U1.11 (PA1)
COL16: J1.9, U1.13 (PA3)
COL17: J1.10, U1.14 (PA4)
COL18: J1.11, U1.15 (PA5)
COL19: J1.12, U1.16 (PA6)
COL20: J1.13, U1.17 (PA7)
D+: J5.3, U1.33 (PA12)
D-: J5.2, U1.32 (PA11)
GND: C5.2, C6.2, C7.2, C8.2, C9.2, C10.2, C11.2, C14.2, C15.2, J1.0, J1.1, J1.20, J2.5, J5.4, J5.MP (MountPin), Q2.2 (S), R1.2, R2.2, U1.8 (VSSA), U1.23 (VSS), U1.35 (VSS), U1.47 (VSS), U3.1 (GND)
LED-: J1.4, Q2.3 (D), R4.2, R5.2, R6.2, R7.2, R8.2, R9.2, R10.2, R11.2, R12.2, R13.2, R14.2, R15.2
LED_CAPS: R22.2, U1.25 (PB12)
LED_NUM: J1.6, U1.6 (PF1)
LED_PWM: R3.1, U1.12 (PA2)
LED_SCLK: J1.19, U1.22 (PB11)
NRST: C5.1, J2.4, U1.7 (NRST)
unnamed: D1.1 (K), R4.1
unnamed: D2.1 (K), R5.1
unnamed: D3.1 (K), R6.1
unnamed: D4.1 (K), R7.1
unnamed: D5.1 (K), R8.1
unnamed: D6.1 (K), R9.1
unnamed: D7.1 (K), R10.1
unnamed: D8.1 (K), R11.1
unnamed: D9.1 (K), R12.1
unnamed: D10.1 (K), R13.1
unnamed: D11.1 (K), R14.1
unnamed: D12.1 (K), R15.1
unnamed: D22.2 (A), MX1.2
unnamed: D23.2 (A), MX2.2
unnamed: D24.2 (A), MX3.2
unnamed: D25.2 (A), MX4.2, MX85.2
unnamed: D26.2 (A), MX5.2
unnamed: D27.2 (A), MX6.2
unnamed: D29.2 (A), MX8.2
unnamed: D30.2 (A), MX9.2
unnamed: D31.2 (A), MX10.2
unnamed: D32.2 (A), MX11.2
unnamed: D34.2 (A), MX13.2
unnamed: D35.2 (A), MX14.2
unnamed: D36.2 (A), MX15.2
unnamed: D37.2 (A), MX16.2
unnamed: D38.2 (A), MX17.2
unnamed: D39.2 (A), MX18.2
unnamed: D40.2 (A), MX19.2
unnamed: D41.2 (A), MX20.2
unnamed: D42.2 (A), MX21.2
unnamed: D43.2 (A), MX22.2
unnamed: D44.2 (A), MX23.2
unnamed: D45.2 (A), MX24.2
unnamed: D46.2 (A), MX25.2
unnamed: D47.2 (A), MX26.2
unnamed: D48.2 (A), MX27.2
unnamed: D49.2 (A), MX28.2
unnamed: D50.2 (A), MX29.2
unnamed: D52.2 (A), MX31.2
unnamed: D53.2 (A), MX32.2
unnamed: D54.2 (A), MX33.2
unnamed: D55.2 (A), MX34.2
unnamed: D56.2 (A), MX35.2
unnamed: D58.2 (A), MX37.2
unnamed: D59.2 (A), MX38.2
unnamed: D60.2 (A), MX39.2
unnamed: D61.2 (A), MX40.2
unnamed: D62.2 (A), MX41.2
unnamed: D64.2 (A), MX43.2
unnamed: D65.2 (A), MX44.2
unnamed: D66.2 (A), MX45.2
unnamed: D67.2 (A), MX46.2
unnamed: D68.2 (A), MX47.2
unnamed: D69.2 (A), MX48.2
unnamed: D70.2 (A), MX49.2
unnamed: D71.2 (A), MX50.2
unnamed: D72.2 (A), MX51.2
unnamed: D73.2 (A), MX52.2
unnamed: D74.2 (A), MX53.2
unnamed: D76.2 (A), MX55.2
unnamed: D77.2 (A), MX56.2
unnamed: D78.2 (A), MX57.2
unnamed: D79.2 (A), MX58.2
unnamed: D80.2 (A), MX59.2
unnamed: D82.2 (A), MX61.2
unnamed: D83.2 (A), MX62.2
unnamed: D84.2 (A), MX63.2
unnamed: D85.2 (A), MX64.2
unnamed: D86.2 (A), MX65.2
unnamed: D87.2 (A), MX66.2
unnamed: D88.2 (A), MX67.2
unnamed: D89.2 (A), MX68.2
unnamed: D90.2 (A), MX69.2
unnamed: D91.2 (A), MX70.2
unnamed: D92.2 (A), MX71.2
unnamed: D93.2 (A), MX72.2
unnamed: D94.2 (A), MX73.2
unnamed: D95.2 (A), MX74.2
unnamed: D96.2 (A), MX75.2
unnamed: D97.2 (A), MX76.2
unnamed: D98.2 (A), MX77.2, MX86.2
unnamed: D100.2 (A), MX79.2
unnamed: D101.2 (A), MX80.2
unnamed: D102.2 (A), MX81.2
unnamed: D104.2 (A), MX83.2, MX87.2
unnamed: D105.2 (A), MX84.2
unnamed: D19.1 (K), D106.1 (K), R22.1
unnamed: Q2.1 (G), R2.1, R3.2
ROW0: D22.1 (K), D34.1 (K), D40.1 (K), D46.1 (K), D52.1 (K), D58.1 (K), D64.1 (K), D70.1 (K), D76.1 (K), D82.1 (K), D88.1 (K), D94.1 (K), D100.1 (K), J1.2, U1.39 (PB3)
ROW1: D23.1 (K), D29.1 (K), D35.1 (K), D41.1 (K), D47.1 (K), D53.1 (K), D59.1 (K), D65.1 (K), D71.1 (K), D77.1 (K), D83.1 (K), D89.1 (K), D95.1 (K), D101.1 (K), J1.14, U1.26 (PB13)
ROW2: D24.1 (K), D30.1 (K), D36.1 (K), D42.1 (K), D48.1 (K), D54.1 (K), D60.1 (K), D66.1 (K), D72.1 (K), D78.1 (K), D84.1 (K), D90.1 (K), D96.1 (K), D102.1 (K), J1.15, U1.18 (PB0)
ROW3: D25.1 (K), D31.1 (K), D37.1 (K), D43.1 (K), D49.1 (K), D55.1 (K), D61.1 (K), D67.1 (K), D73.1 (K), D79.1 (K), D85.1 (K), D91.1 (K), D97.1 (K), J1.16, U1.19 (PB1)
ROW4: D26.1 (K), D32.1 (K), D38.1 (K), D44.1 (K), D50.1 (K), D56.1 (K), D62.1 (K), D68.1 (K), D74.1 (K), D80.1 (K), D86.1 (K), D92.1 (K), D98.1 (K), D104.1 (K), J1.17, U1.20 (PB2)
ROW5: D27.1 (K), D39.1 (K), D45.1 (K), D69.1 (K), D87.1 (K), D93.1 (K), D105.1 (K), J1.18, U1.21 (PB10)
SWC: J2.3, U1.37 (PA14)
SWD: J2.2, U1.34 (PA13)

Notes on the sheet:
Daughterboard
Pin 22 is 5v tolerant. Pin 25 is 5v tolerant. Pin 6 is 5v tolerant. Pin 12 has TIM15_CH1.
Debug
Pin closest to Voltage Regulator
Pin 24
Pin 9
Pin 36
Pin 48
FPC Left Side

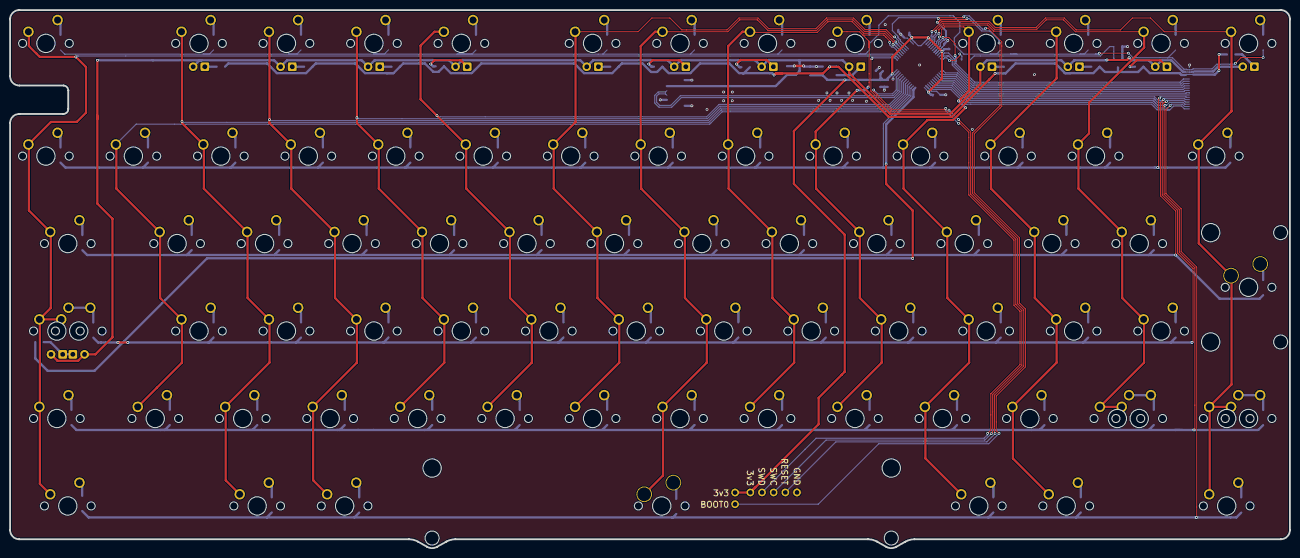
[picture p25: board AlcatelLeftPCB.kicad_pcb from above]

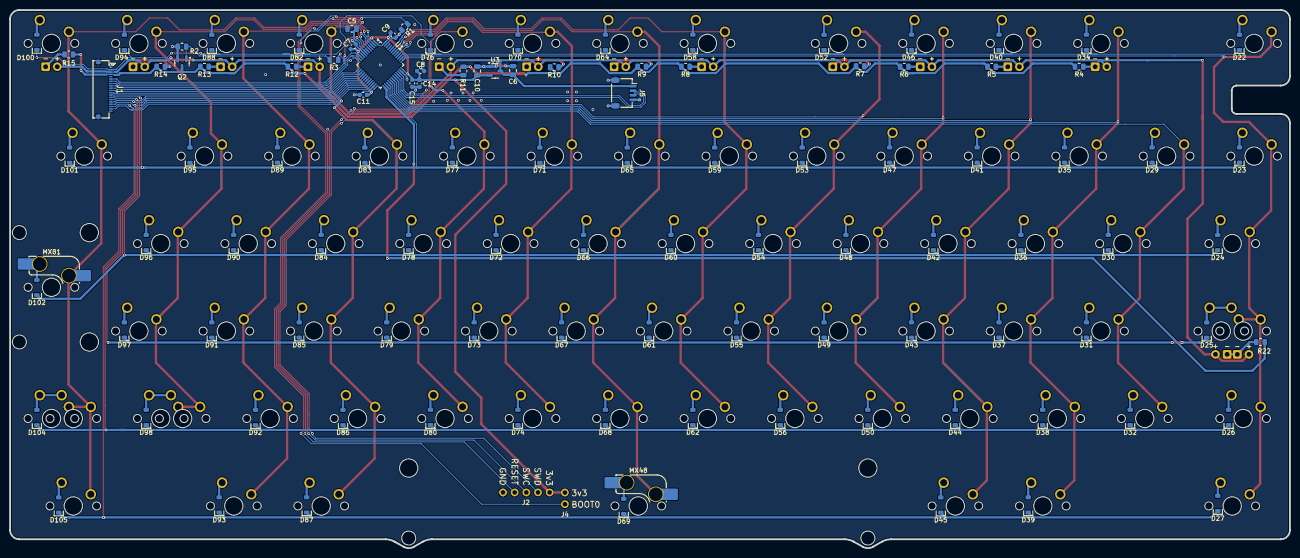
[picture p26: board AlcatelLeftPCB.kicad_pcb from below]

Board: 2 copper layers, 278.7 x 117.2 mm, 201 parts (110 on the bottom side), 130 nets.
